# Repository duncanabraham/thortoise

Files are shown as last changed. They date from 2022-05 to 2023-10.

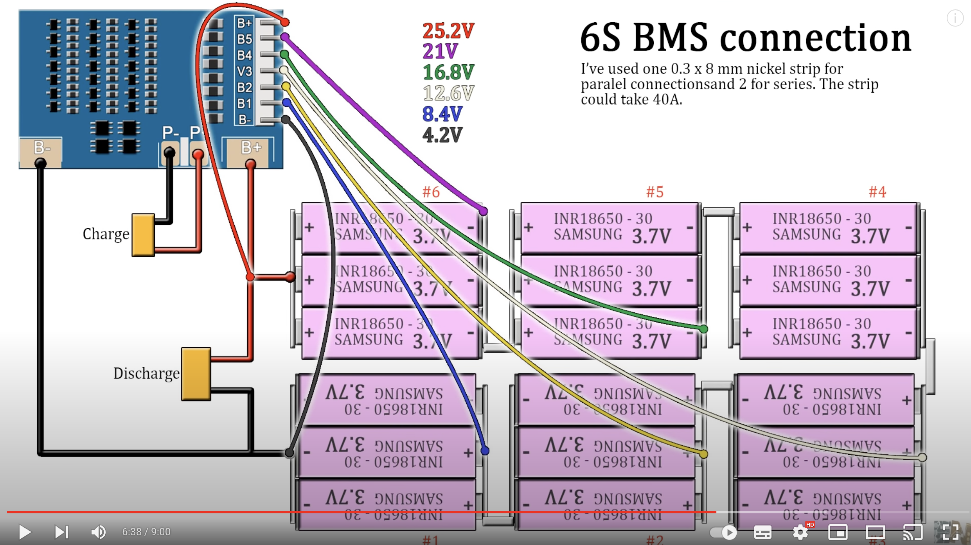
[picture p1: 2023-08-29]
docs/battery-bms.png

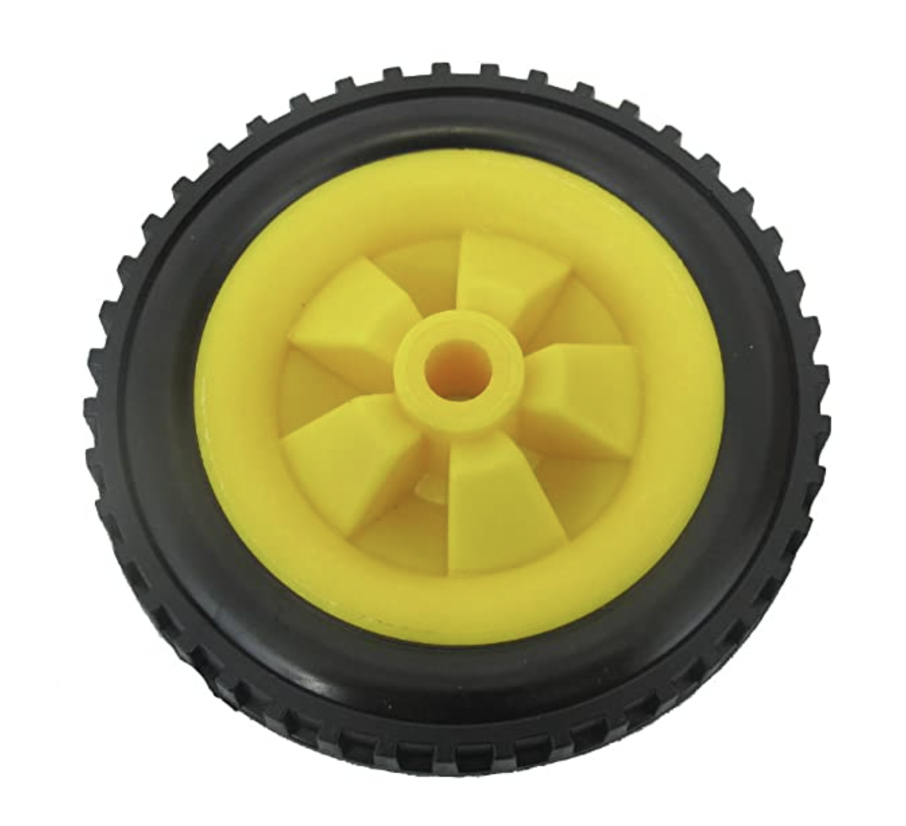
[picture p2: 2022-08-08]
docs/wheels/wheel.png

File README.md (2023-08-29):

# Thortoise
## the thinking tortoise

## What?
Simply put, this is a robotics project to animate a ~~4 legged~~ tracked garden crawler robot.  The goal
is to have a machine that can identify and remove weeds using some AI and also plant grass seed
in the bare patches using the mulched weeds as nutrients.

## Installation
Just clone the repo and npm install .. the usual stuff.

You may have some trouble installing this on a non-Raspberry Pi device, that's just because the raspi-io, i2c-bus and johnny-five libraries may not be supported.
Just remove them from the package.json file before running:

```
npm i
```

After this you need to create your .env file:

```
cp .env-default .env
```
By default the code will use the mock driver which can be used without the physical hardware being connected.

If you want to see lots of numbers relating to the servo angles you need to add this to your .env file:

```
VERBOSE=true
```

## Tests
Hard to believe, I know, but there are tests available here:

```
npm test
```

You'll need mocha and chai installed globally:

```
npm i -g mocha chai
```

## Hardware
Servo driven quadruped with solar charger.
  * Raspberry Pi Zero 2W with hats:
      - servo driver
      - GPS/GNSS
      - Sound
      - Canbus
      - Motor driver (not connected yet)

  * 3d printed limbs
  * Lead acid battery
  * Solar cells etc for changing

## Sensors
A number of sensors have been tested and drivers written to allow them to be added into the system, however not all will be used. Given
all the sensors are i2c based there's a common i2c base library which all the sensors extend.

To reuse the sensors outside of this project, you'll need to remove the inheritance from the Feature class:
```
class I2cBase extends Feature { <-- Remove "extends Feature"
  constructor (options = {}, additional = {}) {
    super({ ...featureOptions, ...options }) <-- Remove this line
    
```
A full list of sensors can be found in the readme file in the [lib/i2c folder](lib/i2c/README.md)

## Software
Lets buck the trend and not use ROS! How about some custom robot code with a redis channel
to allow communication between component parts which could be written in different languages
depending on the task at hand ... or maybe just write it all in good ol' JS!

## The basic components


## A still from a video of the leg moving in a circular gait:


A year later and the legs have gone.  Long story short, the servo's for a walking robot need to be heavy duty which come with a heavy duty price tag.  I decided to switch to a tracked design!

Having tracks means the machine can be heavier and bigger and work is ongoing to 3d print all the structural parts.

As soon as the mechanics of it are constructed I'll get some photos on here and start talking about expectations and features.  Also from an electronics perspective there are some design ideas that will impact the way the code operates.

Watch this space ....

Soooo here we go, I've 3d printed two 64:1 gearboxes using the design from this video: https://www.youtube.com/watch?v=G0DcM60lWSw&t=14s and modified the design to house my motors.  The motors are GARTT ML 5010 300KV with a rated power output of 800W.  The motors were taller than those in the video requiring the black shim you see in the following image, the mounting holes had different spacing and I needed a bigger hole for the cables I'd already soldered 3-way xt60 sockets on and I didn't want to take them off!!



The motors are to be connected to an ODrive motor controller which needs feedback from an encoder. After a couple of minutes with a vernier caliper and OPENScad I'd knocked up an encoder mount that would use the motor mount bolts to secure it in place.  I was happy with this approach and even happier when it was all installed and looking awesome.  The encoder is an AS5047P which has a rated CPR of 4096 but requires the Odrive to be configured as 4000. A magnet is glued to the back of the motor shaft. 4000 steps per turn is an accuracy of 0.09 degrees per step but with the added gearbox this is 0.001 degrees per step which is way more accurate than I need but made me wonder about making an EQ telescope mount .... one day ...





After completion of the main chassis it was time start working on the eletrics.  The motors are high power, as in >30A, so I need to be careful that any switching can handle that sort of current.  To this end I'd bought a 24v 200A relay for the last robot and again was able to reuse this. A low current switch is mounted in the "carry handle" and the wiring routed through the handle to the relay. At present it's a simple case of when the switch is on the Odrive is on but this may change later to allow the "brain" to turn the ODrive off when in power save mode.



It looks messy at the moment but there's a lot of baking soda to shake out of the frame when the gluing process has been completed.  The problem with baking soda is it falls through the cracks and I'm considering using hot glue to seal one side of the joints and baking soda and superglue the other.  I've also see a video showing graphite and superglue as an alternative and I may have a look into this to see if the results are better/stronger.

So with the power cables in place, and the ODrive connected to my PC for direct control, I was finally able to get both motors working at the same time.  Here's a still from the video:



There is a design flaw, which is not entirely of my making, but maybe I should have addressed it.  The gearbox housings are round and I'm going to apply torque to the end, what is going to happen to the gearbox!! My chassis design is a clamshell, so the upper section is a mirror of the lower section and when bolted in place, with some pads on the motors, I can apply a clamping force to the gearbox.  Only time will tell if this is going to be strong enough but in hindsight, when I was modifying the gearbox design I should have added lugs to allow it to be bolted in place ... I may still revisit this.

So here we are, chassis complete, main power control in place, the next step will be to add an enclosure to fit inside the chassis to hold the odrive, pi zero (radxa not raspberry) and power supply. This will provide another level of protection to the important parts should I have water (I have dogs, it could be yellow water) ingress.

I'm also going to reprint the drive cogs as I went with a hexagonal, work like a wrench, approach but again 20:20 hindsight shows that wheels should be round - who knew?

Not round vs Round:



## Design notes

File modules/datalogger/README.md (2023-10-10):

# Data Logger

this is currently running on dev3

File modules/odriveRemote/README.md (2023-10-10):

# Odrive Remote

This runs on the Radxa Zero and performs motor control through an API

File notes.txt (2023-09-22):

Given the robot is approx 500mm square perhaps the grid dimensions should match so each square in 
the grid represents one place where the robot can sit.

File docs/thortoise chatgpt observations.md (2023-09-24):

### 1. Object Recognition and Mapping:

- **Camera and Sensors**: A camera and additional sensors will be essential for object recognition.
- **AI Model**: Implement an AI model capable of identifying plants, watering cans, bare patches, etc., from the camera feed.
- **Object Logger**: Log the positions of recognized objects on the map along with additional metadata like timestamps.

### 2. Decision-Making:

- **Goal Prioritization**: The robot needs to prioritize between different tasks like trimming grass, seeding, researching, etc.
- **Event-Driven Architecture**: Create event triggers based on AI camera identification. For example, when a plant is identified, it triggers a 'SearchForSimilarPlants' event.

### 3. Action Execution:

- **Command Queue**: Extend your existing command queue to handle new types of actions like 'PlantSeeds', 'TrimGrass', etc.
- **Resource Management**: Ensure the robot is aware of its resource limitations (battery life, seed inventory, etc.)

### 4. Learning and Research:

- **Chat API**: Use a chat API to discover information about items found. The robot could query the API for details on how to care for a newly discovered plant species.
- **Learning Loop**: Implement a learning mechanism where the robot refines its decision-making or action execution based on the results of its research.

### 5. Lawn Maintenance:

- **Health Assessment**: Implement algorithms to assess the health of the lawn. This could be a combination of visual cues (brown patches) and sensor data (soil moisture).
- **Adaptive Scheduling**: The robot could adjust its schedule based on the health of the lawn, weather conditions, and other external factors.

### 6. User Interface:

- **Human Overrides**: Keep an option for manual overrides and emergency stops.
- **Monitoring Dashboard**: A dashboard where you can monitor all of the robot’s activities, statuses, and discovered objects.

The architecture you've chosen for the robot seems solid:

1. **ML5010 Drone motors with 64:1 gearboxes**: This provides both speed and torque, ideal for a robot that needs to move efficiently and perform tasks like planting or trimming grass.
2. **Odrive Motor Controller**: A good choice for precision control of your motors.
3. **Radxa Zero**: Responsible for motor control and status LEDs, a quad-core SBC that should manage these tasks quite well.
4. **Raspberry Pi 4**: The main computational unit, responsible for sensor data processing, decision-making, and also serving as a Wi-Fi hotspot for internal and external communication.
5. **Sensor Array**: A comprehensive list of sensors to help the robot navigate and understand its environment.
6. **Power Management**: Using solar panels and LIPO batteries, with channel monitoring to ensure the system remains powered or safely shuts down when needed.
7. **TPU for Machine Learning**: This is a great addition for offloading AI-related processing tasks, freeing up CPU cycles for other things.
8. **AI Camera**: This should be particularly useful for object recognition and distance estimation, important for tasks like identifying plants and obstacles.
9. **Pub/Sub architecture using Redis**: A scalable choice for message-passing within the robot and potentially to external systems.

The internal Wi-Fi network can be a robust solution for real-time control and data sharing between the various components. Using it for Pub/Sub via Redis should make the system very responsive. Plus, the ability to connect a tablet for remote control or logging data to an external database adds another layer of versatility.

### Heartbeat Signal for Radxa Zero

- **Timeout Mechanism**: If the Raspberry Pi 4 doesn't receive a heartbeat from the Radxa Zero within a certain timeframe, it should consider the Radxa to be offline.
- **Default Safe State**: The system could enter a default "safe" state where motors are disabled.
- **Alerts**: The system could also send out an alert (email, SMS, in-app notification, etc.) if the Radxa is not responding as expected.

### Detecting Dogs or Other Animals/Humans

- **AI-based Object Recognition**: Use your AI camera to identify living beings like humans or animals. The robot should stop all movement if such a detection is made.
- **Proximity Sensors**: In addition to visual identification, proximity or ultrasonic sensors can act as an extra layer of detection for nearby objects or beings.
- **Speed Limiting**: When the system detects a living being, it could reduce its speed to a minimum, so that even if there is contact, the impact is minimal.

### Emergency Stop Mechanism

- **Remote Control**: Always have a "kill switch" option available through the tablet or other remote control interfaces.
- **Local Button**: A physical button on the robot itself that can disable all systems immediately.

### Power Failures

- **Low Power Mode**: If the system detects low power levels, it could either safely return to a charging station if one exists or simply stop all operations until manually recovered.
- **Data Preservation**: Before shutting down due to low power, try to preserve essential data to make recovery smoother.

### Monitoring and Alerts

- **Regular System Checks**: Have the system constantly monitor its own health (battery, motor status, sensor status, etc.) and alert if something's not right.
- **External Monitoring**: If possible, set up an external system to monitor the robot's operational status.

By taking these precautions, you'll add an essential layer of safety to your robot, making it better equipped to operate autonomously in a dynamic environment.

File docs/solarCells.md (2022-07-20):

# How to get 17 cells around the inside of dome

external diameter: 400mm
internal diameter: 394mm

solar cell width: 55mm
solar cell height: 110mm

## Outer
* Each side has 17 facets so the angle at the centre is 21.18 degrees (21.18*17 = 360)

## Solving sides to imaginary centre as the sphere is incomplete!
* Solar cell + bracket = 120mm
* distance to solar cell = 200 - wall thickness - bracket thickness = 189

Side a = 120
Side b = 189
Side c = 189

Angle ∠A = 37.019° = 37°1'8" = 0.6461 rad
Angle ∠B = 71.491° = 71°29'26" = 1.24775 rad
Angle ∠C = 71.491° = 71°29'26" = 1.24775 rad

* therefore

## Solving e (distance from top edge to offset centre)
Side a = 160.83798
Side b = 40
Side c = 189

Angle ∠A = 40.763° = 40°45'47" = 0.71145 rad
Angle ∠B = 9.345° = 9°20'43" = 0.1631 rad
Angle ∠C = 129.892° = 129°53'30" = 2.26704 rad

therefore:
* distance to top edge = 160.838mm
* distance to bottom edge = 184.7mm  (sqrt(sqr(189) - sqr(40)))

## Solving the triangle from offset centre to cell base to cell top
Side a = 120
Side b = 160.838
Side c = 184.7

Angle ∠A = 39.896° = 39°53'44" = 0.69631 rad
Angle ∠B = 59.279° = 59°16'45" = 1.03462 rad
Angle ∠C = 80.825° = 80°49'31" = 1.41067 rad

* so the cell tilts inwards 59.2 degrees

## solving the radius to the top edge
Side a = 123.39651
Side b = 103.16086
Side c = 160.838

Angle ∠A = 50.104° = 50°6'14" = 0.87448 rad
Angle ∠B = 39.896° = 39°53'46" = 0.69632 rad
Angle ∠C = 90° = 1.5708 rad = π/2

* so the distance (radius) is 123.397mm

## facet size
* bottom edge = 71.88
* top edge = 55
* bottom offset = (bottomEdge - topEdge) / 2

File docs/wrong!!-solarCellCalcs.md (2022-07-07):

# solar cell calculations

## Outer
* Each side has 18 facets so the angle at the centre is 20 degrees (20*18 = 360)

Side a = 200
Side b = 200
Side c = 69.45927

Angle ∠A = 80° = 1.39626 rad = 4/9π
Angle ∠B = 80° = 1.39626 rad = 4/9π
Angle ∠C = 20° = 0.34907 rad = π/9

* the square across the circumference is 69.459mm

## inner
what size is the inner circle, given the panels are 55mm across

* Each side has 18 facets
* the square across has to be 55mm

Side a = 158.36619
Side b = 158.36619
Side c = 55

Angle ∠A = 80° = 1.39626 rad = 4/9π
Angle ∠B = 80° = 1.39626 rad = 4/9π
Angle ∠C = 20° = 0.34907 rad = π/9

* therefore the inner radius is 158.366

Side a = 158.366
Side b = 110
Side c = 200

Angle ∠A = 52.114° = 52°6'50" = 0.90956 rad
Angle ∠B = 33.243° = 33°14'36" = 0.5802 rad
Angle ∠C = 94.643° = 94°38'35" = 1.65183 rad

* so the bottom angle is 52.1 degrees and the top is 94.64 to the centre

* each large facet is 69.459 and the panel is 55 leaving 14.459 or 7.22 each side
* if the distance between the panels is 14.459mm then the 

Side a = 110
Side b = 110
Side c = 14.459

Angle ∠A = 86.232° = 86°13'54" = 1.50503 rad
Angle ∠B = 86.232° = 86°13'54" = 1.50503 rad
Angle ∠C = 7.537° = 7°32'12" = 0.13154 rad

* the angle between the panels is 7.53 degrees at the top

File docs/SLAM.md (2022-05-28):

# SLAM
## Simultaneous localisation and mapping

So how do we map the world around us into a 2d array that will allow us to:
* discover boundaries
* mark objects of interest
* navigate back to a known position

I think the discovery of boundaries will be a happy accident rather than an established goal.  Thortoise shouldn't set 
off to find the bounds it should just mark them when it finds them.

Our world will be 2d, however, we need to be aware of ground slope and level as this will play a part in navigation
as it will hinder movement in certain directions. Mapping altitude and slope will allow a contour map to be generated 
allowing easiest path planning to be perfomed.

Each element in the world array can contain an map element object.  This can store:
* Slope (from IMU)
* altitude (from GPS)
* actual coordinates (from GPS)
* distance to known features ?
* a photo of the ground at this point (a reference to a photo stored elsewhere)
* an AI analysis of the photo with object recognition
* a list of moveable objects seen at this location
* a list of fixed objects seen at this location

Eventually a complete map of the environment will be formed showing fixed objects, like walls, buildings, trees and 
moveable objects like garden furniture, dog toys and wildlife. The map will also contain a detailed view of the ground 
including plant life, lack of plant life and animal activity. The latter could include worm holes, ant colonies and the
dreaded dog poop.

## The primary objective(s)
1) To erradiate weeds from the lawn
2) To repair the lawn by planting seeds in barren patches
3) To use waste products to enrich the soil, including mulched weed and grass
4) To landscape by filling in divots and dents

## How will it work
We will have data from a number of sources which can all feed into an algorithm to give us an estimated position with 
a high degree of accuracy or reliability.

Sources:
* GPS
* IMU
* Camera(s)

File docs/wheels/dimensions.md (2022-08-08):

# Wheel dimensions

6" or 146mm Trolley wheel with 1/2" bore.

Image analysis:

Bore = 102 pixels
Width = 1108 pixels

Check image against dimensions:
146mm = 1108, therefore 1mm = 7.5 pixels
102 / 7.5 = 13.6mm

if 102 = 12.7mm therefore 1mm = 8 pixels per mm
1108 / 8 = 138.5mm

so it's somewhere between 7.5 and 8 pixels per mm, lets call it 7.75

* top triangle 147 pixels
* outer hub 200 pixels = 200/7.75 = 25.8, probably 1" or 25.4mm
* filled triangle base = 180 pixels = 23.2mm
* there are 5 spokes, the triangles appear to be pointy end in the centre
* Wheel hub = 750pixels = 750/7.75 = 96.77 which is probably 4" which is 101.6mm

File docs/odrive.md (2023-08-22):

In [153]: odrv0.clear_errors()

In [154]: odrv0.axis1.requested_state = AXIS_STATE_FULL_CALIBRATION_SEQUENCE

In [155]: odrv0.axis1.requested_state = AXIS_STATE_CLOSED_LOOP_CONTROL

In [156]: odrv0.axis1.controller.input_pos = 10

In [157]: odrv0.axis1.controller.input_pos = 2

In [158]: odrv0.axis1.controller.input_pos = 200

In [159]: odrv0.axis1.controller.input_pos = 180

In [160]: odrv0.axis1.controller.input_pos = 150

In [161]: odrv0.axis1.controller.input_pos = 130

In [162]: odrv0.axis1.controller.input_pos = 110

In [163]: odrv0.axis1.controller.input_pos = 0

Working after these below:

Connected to ODrive v3.6 207A39994D4D (firmware v0.5.6) as odrv0
In [1]: drv0.axis1.controller.config.control_mode
---------------------------------------------------------------------------
NameError                                 Traceback (most recent call last)
Cell In[1], line 1
----> 1 drv0.axis1.controller.config.control_mode

NameError: name 'drv0' is not defined

In [2]: odrv0.axis1.controller.config.control_mode
Out[2]: 3

In [3]: odrv0.axis1.controller.input_pos
Out[3]: 0.0

In [4]: odrv0.axis1.controller.config.control_mode
Out[4]: 3

In [5]: odrv0.axis1.controller.config.control_mode 2
  Cell In[5], line 1
    odrv0.axis1.controller.config.control_mode 2
                                               ^
SyntaxError: invalid syntax

In [6]: odrv0.axis1.controller.config.control_mode=2

In [7]: odrv0.axis1.requested_state = AXIS_STATE_FULL_CALIBRATION_SEQUENCE

In [8]: odrv0.axis1.requested_state = 8

In [9]: odrv0.axis1.controller.input_vel=32

In [10]: odrv0.axis1.controller.input_vel=0

In [11]: odrv0.axis1.controller.input_vel=8

In [12]: odrv0.axis1.controller.input_vel=16

In [13]: odrv0.axis1.controller.input_vel=0

In [14]:

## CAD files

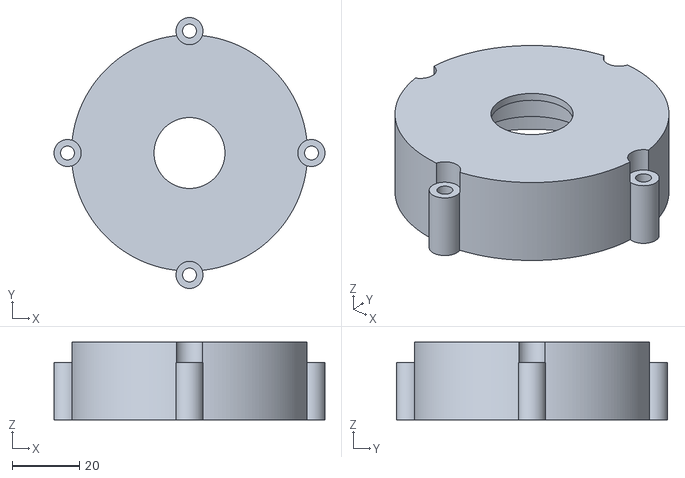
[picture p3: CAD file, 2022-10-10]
cad/gcode/gears-outputEnd.stl
80.3 x 80.3 x 23.0

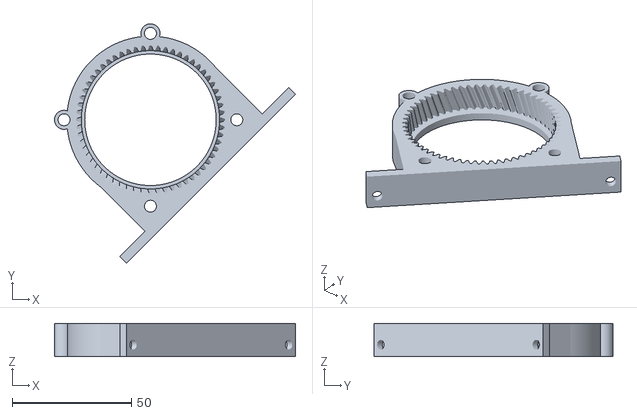
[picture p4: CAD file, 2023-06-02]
cad/gears-half-ring-b.stl
100.9 x 100.2 x 14.0

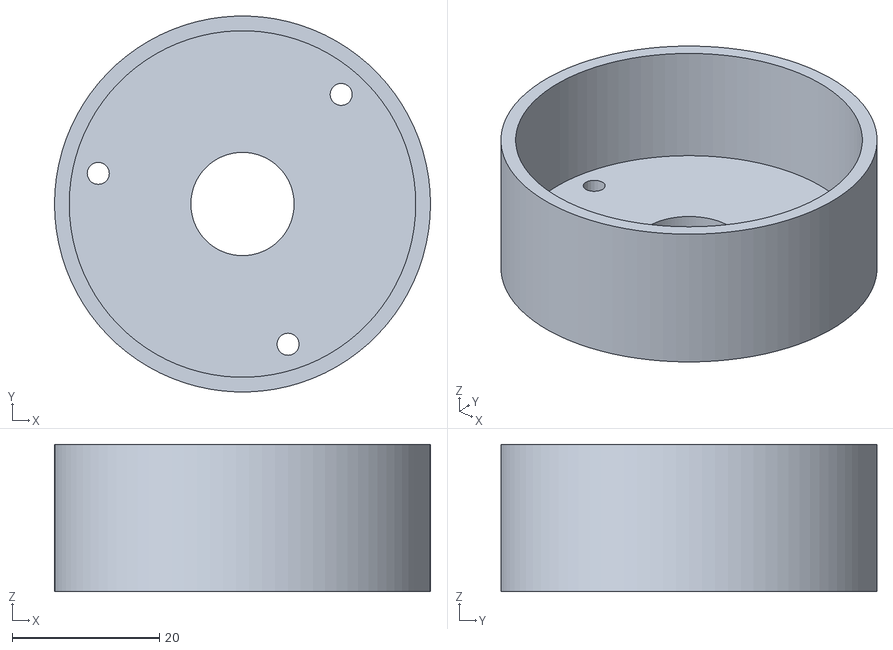
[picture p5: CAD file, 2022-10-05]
cad/gcode/gears-cap.stl
51.0 x 51.0 x 20.0

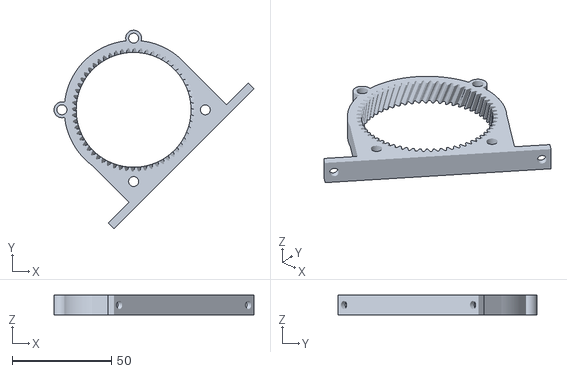
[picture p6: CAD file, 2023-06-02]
cad/gears-half-ring-a.stl
100.9 x 100.2 x 10.0

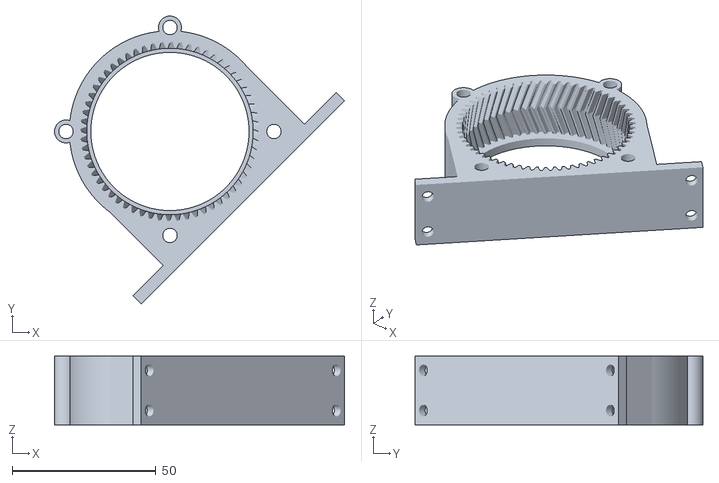
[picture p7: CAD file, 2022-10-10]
cad/gears-outer-ring.stl
100.9 x 100.2 x 24.0

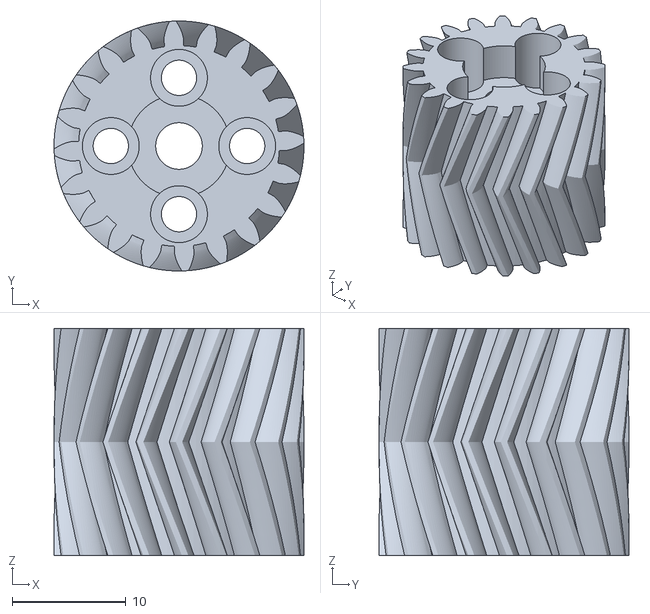
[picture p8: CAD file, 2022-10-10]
cad/gears-sungear.stl
22.0 x 22.0 x 20.0

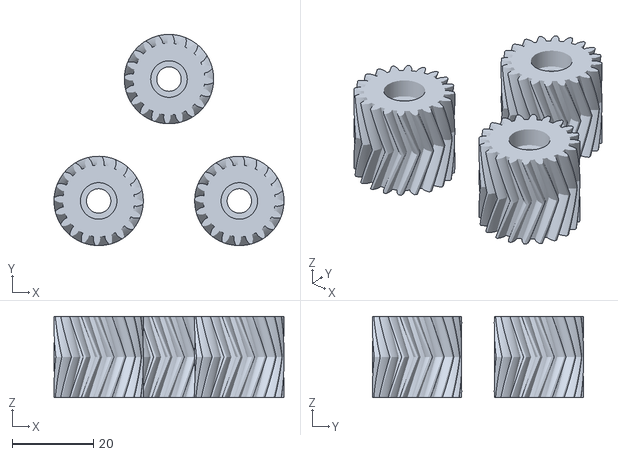
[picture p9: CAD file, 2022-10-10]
cad/gears-planets.stl
56.6 x 52.0 x 20.0

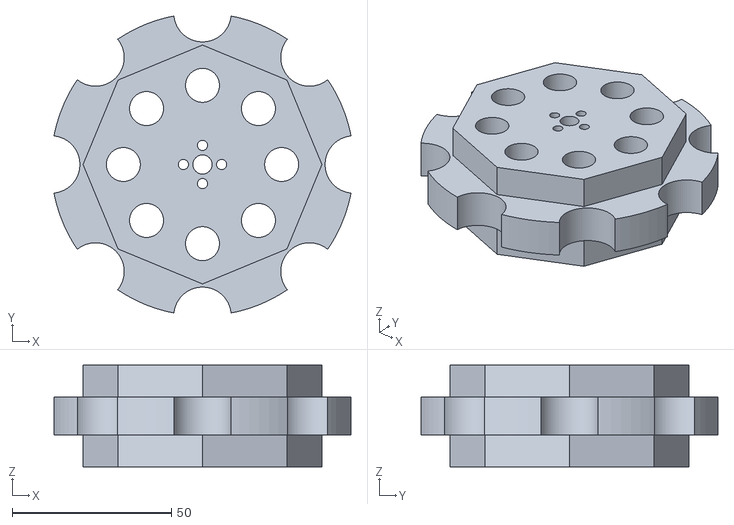
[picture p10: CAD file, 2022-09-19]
cad/spogget-drivecog.stl
93.2 x 93.3 x 32.0

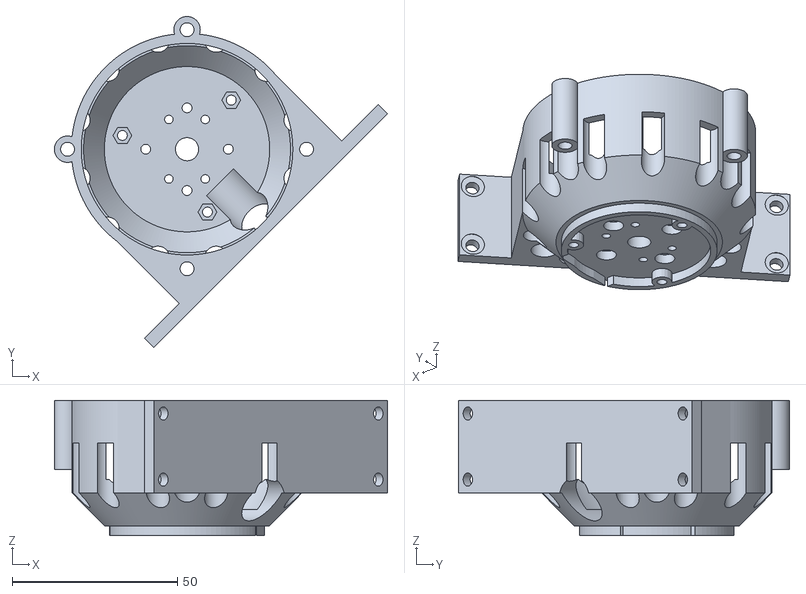
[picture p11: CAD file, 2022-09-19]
cad/gears-motorcell.stl
100.9 x 100.2 x 41.0

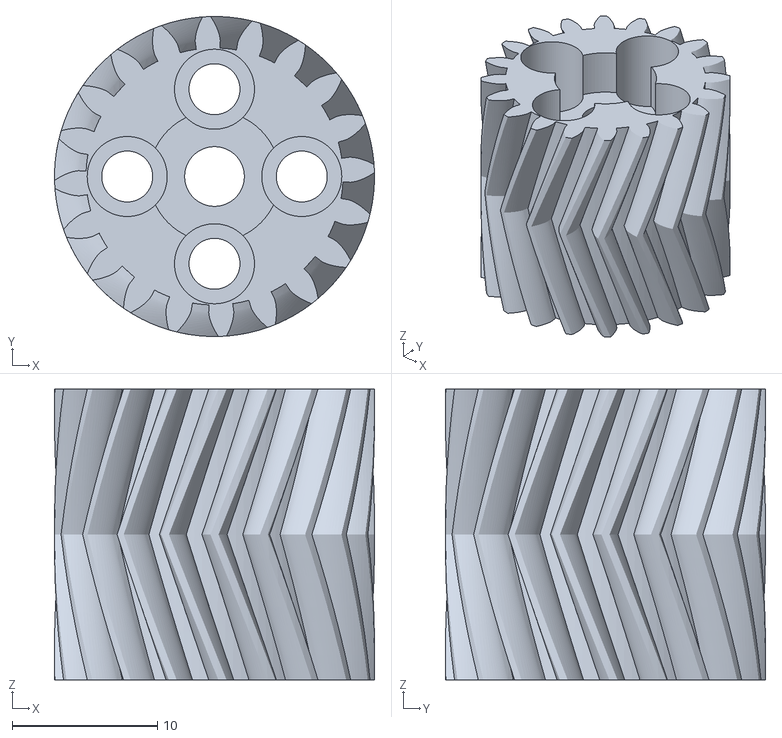
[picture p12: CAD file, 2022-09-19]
cad/gears-sun.stl
22.0 x 22.0 x 20.0

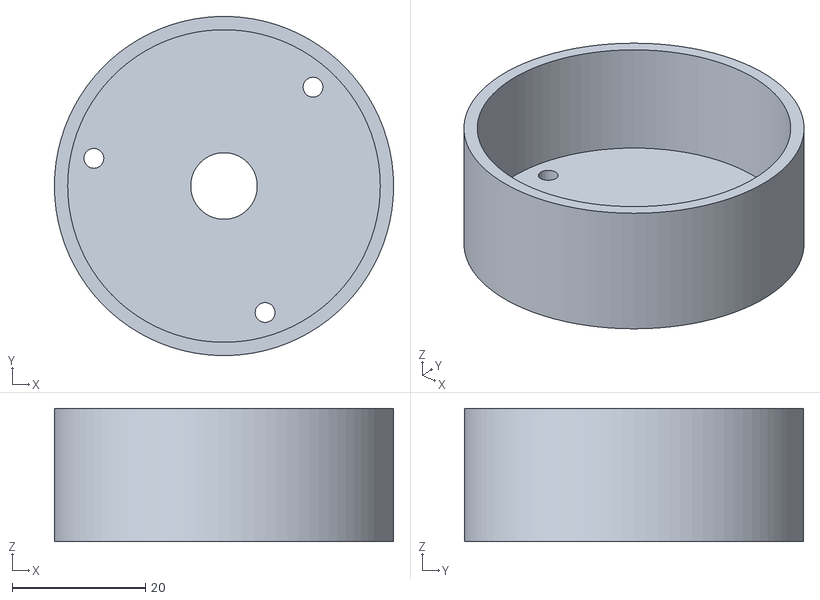
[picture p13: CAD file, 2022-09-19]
cad/gears-cap.stl
51.0 x 51.0 x 20.0

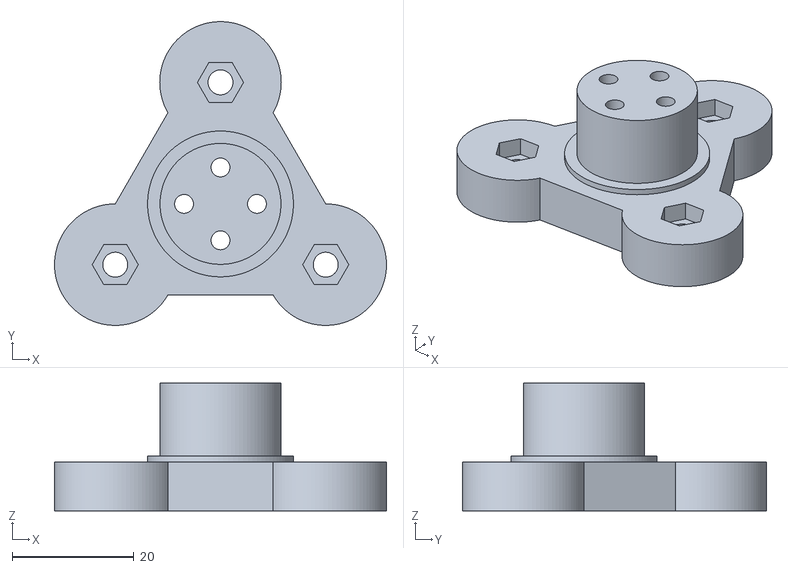
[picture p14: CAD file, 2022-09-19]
cad/gears-planetCarrier.stl
54.6 x 50.0 x 21.0

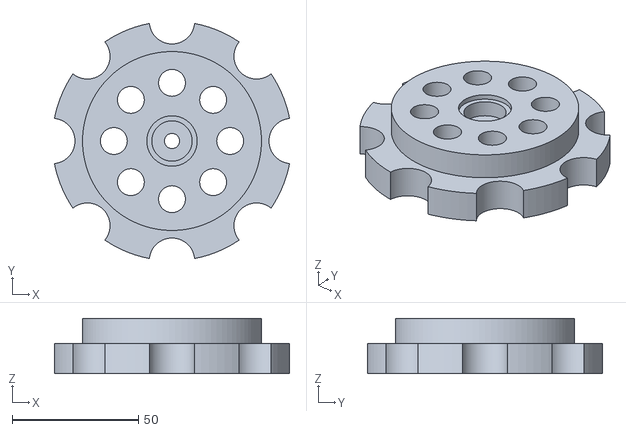
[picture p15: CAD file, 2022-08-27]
cad/spogget-cog-part1.stl
93.2 x 93.3 x 22.0

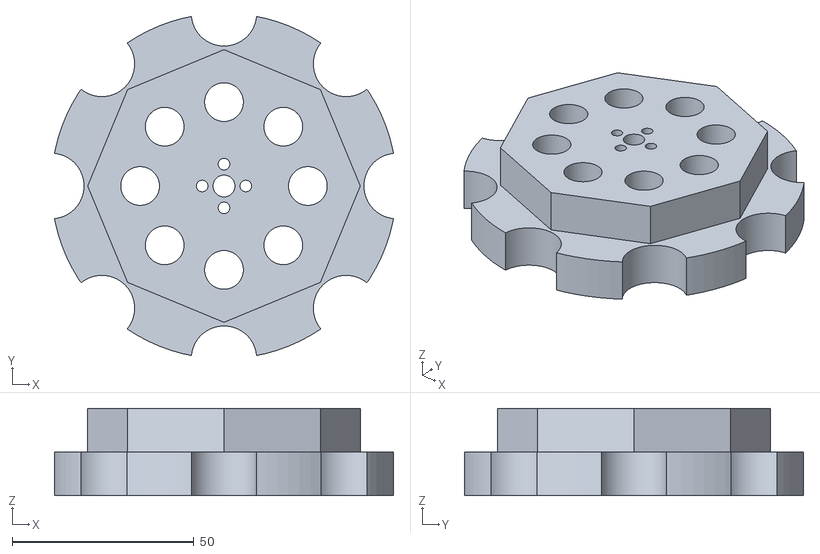
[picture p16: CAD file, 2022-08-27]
cad/spogget-driveCog-part1.stl
93.2 x 93.3 x 24.0

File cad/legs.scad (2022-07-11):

femur = 120;
knee = 120;
width = 20;
pitch = 100;

hwidth = width/2;
hpitch = pitch/2;


module topLimb(x,y,z,a) {
    difference() {
        union(){
            translate([x,y,z]) rotate([0,a,0]) cube([femur, width, width]);
            translate([x,y+hwidth,z]) rotate([0,a,0]) cylinder(d=width*1.5, h=10, $fn=36);
            
            translate([x+femur,y+hwidth,z+hwidth]) rotate([90,90,0]) cylinder(d=width*1.5, h=10, $fn=36);
        }
        union(){
//            translate([x+(femur/3)-1,y-1,z-(pitch/1.8)-1]) rotate([0,90,90]) cylinder(d=femur, h=width+2, $fn=360);
//            translate([x+(femur/3)-1,y-1,z+width+(pitch/1.8)-1]) rotate([0,90,90]) cylinder(d=femur, h=width+2, $fn=360);   
             translate([x+(femur/8)-1,y+width+1,z+width+(pitch/0.9)-1]) rotate([90,0,0]) cylinder(d=femur*2.01, h=width+2, $fn=360); 
        }
    }
}

module lowerLimb(x,y,z,a) {
}

module leftLeg() {
    topLimb(0,0,0,0);
}

module rightLeg() {
    topLimb(0,pitch,0,0);
}

leftLeg();
rightLeg();

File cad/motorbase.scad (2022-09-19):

length = 190;
width = 120;

level2Diameter = 210;

wallThickness = 5;
height = 22.5;
motorWidth = 15;
halfHeight = height /2;

axelBore = 10;
holeDistance = 20;
boreOffset = 12;
fixingOffset = 2.25;
fixingBore = 3;
fixingTop = height-fixingOffset;
reverseFixings = holeDistance + boreOffset;
wireHoleOffset = 40;
wireHoleBoreLength = 25;
wireHoleBoreHeight = 17;
wireHoleBoreHeightStart = (height - wireHoleBoreHeight) / 2;

batteryLength = 151;
batteryWidth = 51;
batteryHeight = 93;

boxHeight = wallThickness + (height * 2);

wheelDiameter = 70;
wheelWidth = 35;

midX=length / 2;
midY=width / 2;

startX = (length - batteryLength) / 2;
startY = (width - batteryWidth) / 2;


module level5() {
    layerHeight =18;
    offsetUp = 25+layerHeight+wallThickness;
    i2cMuxWidth=45;
    i2cMuxLength=81;
    
    lightSensorSpacing=8.5;
    
    powerMonitorWidth=18;
    powerMonitorLength=31.5;
    
    batteryChargerWidth=31.5;
    batteryChargerLength=61.3;
    
    
    difference(){
        union(){
            translate([0,0,boxHeight + wallThickness + offsetUp]) cube([length, width, wallThickness/2]);
            
            translate([(length/2)-80, 5, boxHeight + wallThickness + offsetUp-layerHeight]) 
                cylinder(d=10, h=layerHeight, $fn=90);
            translate([(length/2)-80, width-5, boxHeight + wallThickness + offsetUp-layerHeight]) 
                cylinder(d=10, h=layerHeight, $fn=90);
            translate([(length/2)+80, 5, boxHeight + wallThickness + offsetUp-layerHeight]) 
                cylinder(d=10, h=layerHeight, $fn=90);
            translate([(length/2)+80, width-5, boxHeight + wallThickness + offsetUp-layerHeight]) 
                cylinder(d=10, h=layerHeight, $fn=90);
            translate([(length/2)+30, width-5, boxHeight + wallThickness + offsetUp-layerHeight]) 
                cylinder(d=10, h=layerHeight, $fn=90);
            
            translate([length-80,width-wallThickness,boxHeight + wallThickness + offsetUp - layerHeight]) cube([80, wallThickness, layerHeight]);
            translate([length-wallThickness,width-wallThickness-20,boxHeight + wallThickness + offsetUp - layerHeight]) cube([wallThickness, 20, layerHeight]);
            translate([length-80,width-wallThickness-10,boxHeight + wallThickness + offsetUp - layerHeight]) cube([wallThickness, 10, layerHeight]);
            
        }
        union(){
            fixingHoles();
            
            // i2cMux Mounting
            translate([10, midY-(i2cMuxLength/2), boxHeight + wallThickness + offsetUp-layerHeight]) cylinder(d=2.5, h=50, $fn=90);
            translate([10, midY+(i2cMuxLength/2), boxHeight + wallThickness + offsetUp-layerHeight]) cylinder(d=2.5, h=50, $fn=90);
            translate([10+(i2cMuxWidth), midY-(i2cMuxLength/2), boxHeight + wallThickness + offsetUp-layerHeight]) cylinder(d=2.5, h=50, $fn=90);
            translate([10+(i2cMuxWidth), midY+(i2cMuxLength/2), boxHeight + wallThickness + offsetUp-layerHeight]) cylinder(d=2.5, h=50, $fn=90);
            
            // lightSensor S
            translate([5, midY-(lightSensorSpacing/2), boxHeight + wallThickness + offsetUp-layerHeight]) cylinder(d=5, h=50, $fn=90);
            translate([5, midY+(lightSensorSpacing/2), boxHeight + wallThickness + offsetUp-layerHeight]) cylinder(d=5, h=50, $fn=90);
            
            // lightSensor N
            translate([length-5, midY-(lightSensorSpacing/2), boxHeight + wallThickness + offsetUp-layerHeight]) 
                cylinder(d=5, h=50, $fn=90);
            translate([length-5, midY+(lightSensorSpacing/2), boxHeight + wallThickness + offsetUp-layerHeight])
                cylinder(d=5, h=50, $fn=90);
            
            // lightSensor E
            translate([midX-(lightSensorSpacing/2), 5, boxHeight + wallThickness + offsetUp-layerHeight]) 
                cylinder(d=5, h=50, $fn=90);
            translate([midX+(lightSensorSpacing/2), 5, boxHeight + wallThickness + offsetUp-layerHeight]) 
                cylinder(d=5, h=50, $fn=90);
            
            // lightSensor W
            translate([midX-(lightSensorSpacing/2), width-5, boxHeight + wallThickness + offsetUp-layerHeight]) cylinder(d=5, h=50, $fn=90);
            translate([midX+(lightSensorSpacing/2), width-5, boxHeight + wallThickness + offsetUp-layerHeight]) cylinder(d=5, h=50, $fn=90);
            
            // powerMonitor
            translate([length-20, midY-(powerMonitorLength/2), boxHeight + wallThickness + offsetUp-layerHeight]) cylinder(d=2.5, h=50, $fn=90);
            translate([length-20, midY+(powerMonitorLength/2), boxHeight + wallThickness + offsetUp-layerHeight]) cylinder(d=2.5, h=50, $fn=90);
            translate([length-20-(powerMonitorWidth), midY-(powerMonitorLength/2), boxHeight + wallThickness + offsetUp-layerHeight]) cylinder(d=2.5, h=50, $fn=90);
            translate([length-20-(powerMonitorWidth), midY+(powerMonitorLength/2), boxHeight + wallThickness + offsetUp-layerHeight]) cylinder(d=2.5, h=50, $fn=90);
            
            // batteryCharger
            translate([midX-(batteryChargerWidth/2), midY-(batteryChargerLength/2), boxHeight + wallThickness + offsetUp-layerHeight]) cylinder(d=2.5, h=50, $fn=90);
            translate([midX+(batteryChargerWidth/2), midY-(batteryChargerLength/2), boxHeight + wallThickness + offsetUp-layerHeight]) cylinder(d=2.5, h=50, $fn=90);
            
            translate([midX-(batteryChargerWidth/2), midY+(batteryChargerLength/2), boxHeight + wallThickness + offsetUp-layerHeight]) cube([batteryChargerWidth, 10, 50]);
            
            // Cable Slot 1
            slotWidth = batteryChargerWidth * 2.2;
            translate([59, midY-(slotWidth/2), boxHeight + wallThickness + offsetUp-layerHeight]) cube([12, slotWidth, 100]);
            
            // Cable Slot 2
            translate([length-60, midY-(batteryChargerWidth/2), boxHeight + wallThickness + offsetUp-layerHeight]) cube([10, batteryChargerWidth, 100]);
            
            // GPS Mount
            translate([length-10,20, boxHeight + wallThickness + offsetUp-layerHeight]) cylinder(d=6.4, h=25, $fn=90);
            
            // Switch 
            translate([length-40,width-wallThickness-1,boxHeight + wallThickness + offsetUp - layerHeight + 9]) rotate([0,90,90]) cylinder(d=12, h=10, $fn=90);
        }
    }
}

module level4() {   
    offsetUp = 25;
    difference(){
        union(){
            translate([0,0,boxHeight + wallThickness + offsetUp]) cube([length, width, wallThickness]);
            translate([midX,midY, boxHeight+wallThickness + offsetUp]) cylinder(d=level2Diameter*0.7, h=wallThickness, $fn=90);
            translate([startX - 5, startY - 5, boxHeight + wallThickness+wallThickness+wallThickness]) cube([batteryLength+10, batteryWidth+10, offsetUp-wallThickness]);
        }
        union(){
            translate([5, motorWidth + wallThickness, boxHeight-10+offsetUp]) cylinder(d=5, h=boxHeight, $fn=90);
            translate([5, width - (motorWidth + wallThickness), boxHeight-10+offsetUp]) cylinder(d=5, h=boxHeight, $fn=90);
            translate([length-5, motorWidth + wallThickness, boxHeight-10+offsetUp]) cylinder(d=5, h=boxHeight, $fn=90);
            translate([length-5, width - (motorWidth + wallThickness), boxHeight-10+offsetUp]) cylinder(d=5, h=boxHeight, $fn=90);
            battery();
            fixingHoles();
        }
    }
    cameraBracket();
}

module level3() {   
    offsetUp = 0;
    difference(){
        union(){
            translate([0,0,boxHeight + wallThickness + offsetUp]) cube([length, width, wallThickness]);
            translate([midX,midY, boxHeight+wallThickness + offsetUp]) cylinder(d=level2Diameter*0.9, h=wallThickness, $fn=90);
            translate([startX - 5, startY - 5, boxHeight + wallThickness + offsetUp]) cube([batteryLength+10, batteryWidth+10, 20]);
        }
        union(){
            translate([5, motorWidth + wallThickness, boxHeight-10+offsetUp]) cylinder(d=5, h=boxHeight, $fn=90);
            translate([5, width - (motorWidth + wallThickness), boxHeight-10+offsetUp]) cylinder(d=5, h=boxHeight, $fn=90);
            translate([length-5, motorWidth + wallThickness, boxHeight-10+offsetUp]) cylinder(d=5, h=boxHeight, $fn=90);
            translate([length-5, width - (motorWidth + wallThickness), boxHeight-10+offsetUp]) cylinder(d=5, h=boxHeight, $fn=90);
            battery();
            fixingHoles();
        }
    }
}

module battery() {
    translate([startX, startY, wallThickness]) color([0,0,0]) cube([batteryLength, batteryWidth, batteryHeight]);
}


module level2() {

    difference(){
        union(){
            translate([midX,midY, height+wallThickness]) cylinder(d=level2Diameter, h=wallThickness, $fn=90);
            translate([0,0,wallThickness+height]) cube([length, width, wallThickness]);
        }
        union(){
            fixingHoles();
            battery();
        }
    }
}
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

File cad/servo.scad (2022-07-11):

servoLength=42;
servoWidth=20;
servoHeight=36;
servoFlangeHeight=28;
fullLength=54;
flangeOffset = (fullLength - servoLength) / 2;
flangeMountHolesLength=50;
flangeHeight=2.5;
driveMountHeight=3;
driveMountWidth=10;

hipLength=60;
hipHeight=37;
hipWidth=60;


module servo(x,y,z) {
    difference(){
        union(){
            translate([x+flangeOffset,y,z]) cube([servoLength, servoWidth, servoHeight]);
            translate([x,y,z+servoFlangeHeight]) cube([fullLength, servoWidth, flangeHeight]);
            translate([x+fullLength-flangeOffset-16, y+10, z+servoHeight+3]) cylinder(d=5, h=7, $fn=36);
            translate([x+fullLength-flangeOffset-16, y+10, z+servoHeight]) cylinder(r=driveMountWidth, h=4, $fn=36);
            translate([x+fullLength-flangeOffset,y+4,z+4]) cube([flangeOffset, servoWidth-8, flangeHeight*2]);
        }
        union(){
            translate([x+2, y+5, z+servoFlangeHeight-1]) cylinder(d=4, h=4, $fn=36);
            translate([x+2, y+15, z+servoFlangeHeight-1]) cylinder(d=4, h=4, $fn=36);
            translate([x+fullLength-2, y+5, z+servoFlangeHeight-1]) cylinder(d=4, h=4, $fn=36);
            translate([x+fullLength-2, y+15, z+servoFlangeHeight-1]) cylinder(d=4, h=4, $fn=36);
        }
    }
}

module bracket(x,y,z) {
    difference(){
        union(){
            translate([x,y-3,z-1]) rotate([0,-90,-90]) color([0,1,0]) cube([hipHeight, fullLength+10, 2]);
            translate([x,y+servoWidth+1,z-1]) rotate([0,-90,-90]) color([0,1,0]) cube([hipHeight, fullLength+10, 2]);
            
            translate([x,y-3,z+servoFlangeHeight-6]) color([0,1,0]) cube([flangeOffset-1, servoWidth+4, 6]);
            translate([x,y-3,z+servoFlangeHeight-15]) color([0,1,0]) cube([flangeOffset-1, servoWidth+4, 4]);
            
            translate([x+fullLength,y-3,z+servoFlangeHeight-6]) color([0,1,0]) cube([flangeOffset-1+5, servoWidth+4, 8.5]);
            translate([x+fullLength-5,y-3,z+servoFlangeHeight-6]) color([0,1,0]) cube([flangeOffset-1+10, servoWidth+4, 6]);
            translate([x+fullLength-5,y-3,z+servoFlangeHeight-15]) color([0,1,0]) cube([flangeOffset-1+10, servoWidth+4, 4]);
            
            translate([x,y-3,z-3]) rotate([0,-90,-90]) color([0,1,0]) cube([2, fullLength+10, 26]);
            translate([x+fullLength-flangeOffset-16, y+10, z-8]) color([0,1,0]) cylinder(d=6, h=6, $fn=36);
        }
        union(){
            translate([x+2, y+5, z+servoFlangeHeight-20]) cylinder(d=4, h=24, $fn=36);
            translate([x+2, y+15, z+servoFlangeHeight-20]) cylinder(d=4, h=24, $fn=36);
            translate([x+fullLength-2, y+5, z+servoFlangeHeight-20]) cylinder(d=4, h=24, $fn=36);
            translate([x+fullLength-2, y+15, z+servoFlangeHeight-20]) cylinder(d=4, h=24, $fn=36);
        }
    }
}

module hip(x,y,z) {

}

module femur(x,y,z) {
    servo(x,y,z);
    bracket(x,y,z);
    
    rotate([0,0,225])
    difference(){
        x=x+0.5;
        y=y-20.5;
        union(){
            bracket(x,y,z);
            servo(x,y,z);
            rotate([0,0,66]) translate([x-22,y+10,z-3]) color([0,1,0]) cube([2,18.7,39]);
            rotate([0,-90,0]) translate([x-3.5,y-2,z-2]) color([0,1,0]) cube([2,25,18]);
        }
        union(){
            
            rotate([0,-90,0]) translate([x,y-25.8,z-2]) rotate([0,24,90]) color([0,1,0]) cube([20,10,30]);
            translate([x+fullLength+2,y-4,z+servoFlangeHeight-33]) cube([20,30,43]);
        }
    }
}

module knee(x,y,z) {
    difference(){
        rotate([0,0,0]) union(){
            translate([x,y-0.5,z-6]) color([0,0,1]) cube([90,30,hipHeight+17]);
            translate([x+fullLength-flangeOffset+42, y+14.5, z+servoHeight+7]) color([0,0,1]) cylinder(d=30, h=5, $fn=120);
            translate([x+fullLength-flangeOffset+42, y+14.5, z+servoHeight-42]) color([0,0,1]) cylinder(d=30, h=5, $fn=120);
        }
        union(){
            translate([x+55,y-1,z-1]) color([0,0,1]) cube([40,32,hipHeight+7]);
            translate([x+fullLength-flangeOffset+42, y+14.5, z+servoHeight+6]) color([0,0,1]) cylinder(d=5, h=10, $fn=120);
            translate([x+fullLength-flangeOffset+42, y+14.5, z+servoHeight-43]) color([0,0,1]) cylinder(d=16, h=7.5, $fn=120);
        }
    }
}


hip(0,0,0);
femur(0,0,0);
knee(-120,-30,-3);

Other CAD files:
cad/gears-output.stl
cad/spogget-driveCog-part2.stl
cad/spogget-cog-part2.stl
cad/spogget.stl
cad/wheel.scad
cad/F_shoulder.stl
cad/HexaLeg.3mf
cad/R_shoulder.stl
cad/Snow_Track1.STL
cad/baseplate.scad
cad/baseplate.stl
cad/basicBase.stl
cad/batterybox.scad
cad/bottomBracket.3mf
cad/bottomBracket.stl
cad/box-lid.stl
cad/box.scad
cad/box.stl
cad/box2.scad
cad/box2.stl
cad/box3.scad
cad/box3.stl
cad/box4.scad
cad/box4.stl
cad/brackets.scad
cad/cameraHolder.scad
cad/drive_spogget.stl
cad/femur.scad
cad/gears-outerRing.stl
cad/gears.scad
cad/gearsgen.scad
cad/lightHolder.scad
cad/lightHolder.stl
cad/motorbase.stl
cad/motorbaseCameraBracket.stl
cad/motorbaseLevel2.stl
cad/motorbaseLevel3.stl
cad/motorbaseLevel4.stl
cad/motorbaseLevel5.stl
cad/motorbaseLid.stl
cad/newBracket.scad
cad/solarcells-2.3mf
cad/solarcells-2.stl
cad/solarcells-new.stl
cad/solarcells.scad
cad/solarcells.stl
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

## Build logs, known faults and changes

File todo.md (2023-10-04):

# TODO

Still lots to do. How is this going to work?

* DONE - get bearing from IMU
* DONE - get location from GPS ??
* DONE - get direction from compass
* DONE - read light levels from sensors
* map location to internal map
* DONE - provide a way to save and load the map to disk
* DONE - provide a way to save and load the map from external server
* add commands to the api controller for:
  - Navigate to North, South, East, West
  - Walk: giving the current bearing and direction command, what coords should I move to
  - Goto: given destination coordinates, work out the next location to walk to. On the next turn, work it out again as the map could have been updated by then

* DONE - provide a list of commands, allow "goto" to enter a set of commands into the list
* let the system determine if a command is complete and we're ready to move on to the next command
* at each location take a picture of the ground (pi cam) and update the map
* Use the AI camera to provide object detection and use this to update the map
* Use the AI camera to determine distance to objects and use this to update the map
* Use a directive engine to determine what to do in the absense of API commands
* Use the sound card to announce what's going on
* Use the UART Hat GPIO to control the LEDs on the head
* DONE - Connect the solar cells to the charge controller
* DONE - needs work - Make a framework to support the solar cells
* DONE - needs more work around charging times - Use the charge monitor to determine charge, charging rate etc

** NOTE: I'm not sure this list is worth maintaining as it was written pre-legs!!

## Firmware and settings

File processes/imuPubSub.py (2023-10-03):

import time
import smbus
import math
import redis
import json

r = redis.Redis(host='localhost', port=6379, db=0)

Gyro  = [0,0,0]
Accel = [0,0,0]
Mag   = [0,0,0]
pitch = 0.0
roll  = 0.0
yaw   = 0.0
pu8data=[0,0,0,0,0,0,0,0]
U8tempX=[0,0,0,0,0,0,0,0,0]
U8tempY=[0,0,0,0,0,0,0,0,0]
U8tempZ=[0,0,0,0,0,0,0,0,0]
GyroOffset=[0,0,0]
Ki = 1.0
Kp = 4.50
q0 = 1.0
q1=q2=q3=0.0
angles=[0.0,0.0,0.0]
true                                 =0x01
false                                =0x00
# define ICM-20948 Device I2C address
I2C_ADD_ICM20948                     = 0x68
I2C_ADD_ICM20948_AK09916             = 0x0C
I2C_ADD_ICM20948_AK09916_READ        = 0x80
I2C_ADD_ICM20948_AK09916_WRITE       = 0x00
# define ICM-20948 Register
# user bank 0 register
REG_ADD_WIA                          = 0x00
REG_VAL_WIA                          = 0xEA
REG_ADD_USER_CTRL                    = 0x03
REG_VAL_BIT_DMP_EN                   = 0x80
REG_VAL_BIT_FIFO_EN                  = 0x40
REG_VAL_BIT_I2C_MST_EN               = 0x20
REG_VAL_BIT_I2C_IF_DIS               = 0x10
REG_VAL_BIT_DMP_RST                  = 0x08
REG_VAL_BIT_DIAMOND_DMP_RST          = 0x04
REG_ADD_PWR_MIGMT_1                  = 0x06
REG_VAL_ALL_RGE_RESET                = 0x80
REG_VAL_RUN_MODE                     = 0x01 # Non low-power mode
REG_ADD_LP_CONFIG                    = 0x05
REG_ADD_PWR_MGMT_1                   = 0x06
REG_ADD_PWR_MGMT_2                   = 0x07
REG_ADD_ACCEL_XOUT_H                 = 0x2D
REG_ADD_ACCEL_XOUT_L                 = 0x2E
REG_ADD_ACCEL_YOUT_H                 = 0x2F
REG_ADD_ACCEL_YOUT_L                 = 0x30
REG_ADD_ACCEL_ZOUT_H                 = 0x31
REG_ADD_ACCEL_ZOUT_L                 = 0x32
REG_ADD_GYRO_XOUT_H                  = 0x33
REG_ADD_GYRO_XOUT_L                  = 0x34
REG_ADD_GYRO_YOUT_H                  = 0x35
REG_ADD_GYRO_YOUT_L                  = 0x36
REG_ADD_GYRO_ZOUT_H                  = 0x37
REG_ADD_GYRO_ZOUT_L                  = 0x38
REG_ADD_EXT_SENS_DATA_00             = 0x3B
REG_ADD_REG_BANK_SEL                 = 0x7F
REG_VAL_REG_BANK_0                   = 0x00
REG_VAL_REG_BANK_1                   = 0x10
REG_VAL_REG_BANK_2                   = 0x20
REG_VAL_REG_BANK_3                   = 0x30

# user bank 1 register
# user bank 2 register
REG_ADD_GYRO_SMPLRT_DIV              = 0x00
REG_ADD_GYRO_CONFIG_1                = 0x01
REG_VAL_BIT_GYRO_DLPCFG_2            = 0x10  # bit[5:3]
REG_VAL_BIT_GYRO_DLPCFG_4            = 0x20  # bit[5:3]
REG_VAL_BIT_GYRO_DLPCFG_6            = 0x30  # bit[5:3]
REG_VAL_BIT_GYRO_FS_250DPS           = 0x00  # bit[2:1]
REG_VAL_BIT_GYRO_FS_500DPS           = 0x02  # bit[2:1]
REG_VAL_BIT_GYRO_FS_1000DPS          = 0x04  # bit[2:1]
REG_VAL_BIT_GYRO_FS_2000DPS          = 0x06  # bit[2:1]
REG_VAL_BIT_GYRO_DLPF                = 0x01  # bit[0]
REG_ADD_ACCEL_SMPLRT_DIV_2           = 0x11
REG_ADD_ACCEL_CONFIG                 = 0x14
REG_VAL_BIT_ACCEL_DLPCFG_2           = 0x10  # bit[5:3]
REG_VAL_BIT_ACCEL_DLPCFG_4           = 0x20  # bit[5:3]
REG_VAL_BIT_ACCEL_DLPCFG_6           = 0x30  # bit[5:3]
REG_VAL_BIT_ACCEL_FS_2g              = 0x00  # bit[2:1]
REG_VAL_BIT_ACCEL_FS_4g              = 0x02  # bit[2:1]
REG_VAL_BIT_ACCEL_FS_8g              = 0x04  # bit[2:1]
REG_VAL_BIT_ACCEL_FS_16g             = 0x06  # bit[2:1]
REG_VAL_BIT_ACCEL_DLPF               = 0x01  # bit[0]

# user bank 3 register
REG_ADD_I2C_SLV0_ADDR                = 0x03
REG_ADD_I2C_SLV0_REG                 = 0x04
REG_ADD_I2C_SLV0_CTRL                = 0x05
REG_VAL_BIT_SLV0_EN                  = 0x80
REG_VAL_BIT_MASK_LEN                 = 0x07
REG_ADD_I2C_SLV0_DO                  = 0x06
REG_ADD_I2C_SLV1_ADDR                = 0x07
REG_ADD_I2C_SLV1_REG                 = 0x08
REG_ADD_I2C_SLV1_CTRL                = 0x09
REG_ADD_I2C_SLV1_DO                  = 0x0A

# define ICM-20948 Register  end

# define ICM-20948 MAG Register
REG_ADD_MAG_WIA1                     = 0x00
REG_VAL_MAG_WIA1                     = 0x48
REG_ADD_MAG_WIA2                     = 0x01
REG_VAL_MAG_WIA2                     = 0x09
REG_ADD_MAG_ST2                      = 0x10
REG_ADD_MAG_DATA                     = 0x11
REG_ADD_MAG_CNTL2                    = 0x31
REG_VAL_MAG_MODE_PD                  = 0x00
REG_VAL_MAG_MODE_SM                  = 0x01
REG_VAL_MAG_MODE_10HZ                = 0x02
REG_VAL_MAG_MODE_20HZ                = 0x04
REG_VAL_MAG_MODE_50HZ                = 0x05
REG_VAL_MAG_MODE_100HZ               = 0x08
REG_VAL_MAG_MODE_ST                  = 0x10
# define ICM-20948 MAG Register  end

MAG_DATA_LEN                         =6

class ICM20948(object):
  def __init__(self,address=I2C_ADD_ICM20948):
    self._address = address
    self._bus = smbus.SMBus(1)
    bRet=self.icm20948Check()             #Initialization of the device multiple times after power on will result in a return error
    # while true != bRet:
    #   print("ICM-20948 Error\n" )
    #   time.sleep(0.5)
    # print("ICM-20948 OK\n" )
    time.sleep(0.5)                       #We can skip this detection by delaying it by 500 milliseconds
    # user bank 0 register 
    self._write_byte( REG_ADD_REG_BANK_SEL , REG_VAL_REG_BANK_0)
    self._write_byte( REG_ADD_PWR_MIGMT_1 , REG_VAL_ALL_RGE_RESET)
    time.sleep(0.1)
    self._write_byte( REG_ADD_PWR_MIGMT_1 , REG_VAL_RUN_MODE)  
    #user bank 2 register
    self._write_byte( REG_ADD_REG_BANK_SEL , REG_VAL_REG_BANK_2)
    self._write_byte( REG_ADD_GYRO_SMPLRT_DIV , 0x07)
    self._write_byte( REG_ADD_GYRO_CONFIG_1 , REG_VAL_BIT_GYRO_DLPCFG_6 | REG_VAL_BIT_GYRO_FS_1000DPS | REG_VAL_BIT_GYRO_DLPF)
    self._write_byte( REG_ADD_ACCEL_SMPLRT_DIV_2 ,  0x07)
    self._write_byte( REG_ADD_ACCEL_CONFIG , REG_VAL_BIT_ACCEL_DLPCFG_6 | REG_VAL_BIT_ACCEL_FS_2g | REG_VAL_BIT_ACCEL_DLPF)
    #user bank 0 register
    self._write_byte( REG_ADD_REG_BANK_SEL , REG_VAL_REG_BANK_0) 
    time.sleep(0.1)
    self.icm20948GyroOffset()
    self.icm20948MagCheck()
    self.icm20948WriteSecondary( I2C_ADD_ICM20948_AK09916|I2C_ADD_ICM20948_AK09916_WRITE,REG_ADD_MAG_CNTL2, REG_VAL_MAG_MODE_20HZ)
  def icm20948_Gyro_Accel_Read(self):
    self._write_byte( REG_ADD_REG_BANK_SEL , REG_VAL_REG_BANK_0)
    data =self._read_block(REG_ADD_ACCEL_XOUT_H, 12)
    self._write_byte( REG_ADD_REG_BANK_SEL , REG_VAL_REG_BANK_2)
    Accel[0] = (data[0]<<8)|data[1]
    Accel[1] = (data[2]<<8)|data[3]
    Accel[2] = (data[4]<<8)|data[5]
    Gyro[0]  = ((data[6]<<8)|data[7]) - GyroOffset[0]
    Gyro[1]  = ((data[8]<<8)|data[9]) - GyroOffset[1]
    Gyro[2]  = ((data[10]<<8)|data[11]) - GyroOffset[2]
    if Accel[0]>=32767:             #Solve the problem that Python shift will not overflow
      Accel[0]=Accel[0]-65535
    elif Accel[0]<=-32767:
      Accel[0]=Accel[0]+65535
    if Accel[1]>=32767:
      Accel[1]=Accel[1]-65535
    elif Accel[1]<=-32767:
      Accel[1]=Accel[1]+65535
    if Accel[2]>=32767:
      Accel[2]=Accel[2]-65535
    elif Accel[2]<=-32767:
      Accel[2]=Accel[2]+65535
    if Gyro[0]>=32767:
      Gyro[0]=Gyro[0]-65535
    elif Gyro[0]<=-32767:
      Gyro[0]=Gyro[0]+65535
    if Gyro[1]>=32767:
      Gyro[1]=Gyro[1]-65535
    elif Gyro[1]<=-32767:
      Gyro[1]=Gyro[1]+65535
    if Gyro[2]>=32767:
      Gyro[2]=Gyro[2]-65535
    elif Gyro[2]<=-32767:
      Gyro[2]=Gyro[2]+65535
  def icm20948MagRead(self):
    counter=20
    while(counter>0):
      time.sleep(0.01)
      self.icm20948ReadSecondary( I2C_ADD_ICM20948_AK09916|I2C_ADD_ICM20948_AK09916_READ , REG_ADD_MAG_ST2, 1)
      if ((pu8data[0] & 0x01)!= 0):
        break
      counter-=1
    if counter!=0:
      for i in range(0,8):
        self.icm20948ReadSecondary( I2C_ADD_ICM20948_AK09916|I2C_ADD_ICM20948_AK09916_READ , REG_ADD_MAG_DATA , MAG_DATA_LEN)
        U8tempX[i] = (pu8data[1]<<8)|pu8data[0]
        U8tempY[i] = (pu8data[3]<<8)|pu8data[2]
        U8tempZ[i] = (pu8data[5]<<8)|pu8data[4]
      Mag[0]=(U8tempX[0]+U8tempX[1]+U8tempX[2]+U8tempX[3]+U8tempX[4]+U8tempX[5]+U8tempX[6]+U8tempX[7])/8
      Mag[1]=-(U8tempY[0]+U8tempY[1]+U8tempY[2]+U8tempY[3]+U8tempY[4]+U8tempY[5]+U8tempY[6]+U8tempY[7])/8
      Mag[2]=-(U8tempZ[0]+U8tempZ[1]+U8tempZ[2]+U8tempZ[3]+U8tempZ[4]+U8tempZ[5]+U8tempZ[6]+U8tempZ[7])/8
    if Mag[0]>=32767:            #Solve the problem that Python shift will not overflow
      Mag[0]=Mag[0]-65535
    elif Mag[0]<=-32767:
      Mag[0]=Mag[0]+65535
    if Mag[1]>=32767:
      Mag[1]=Mag[1]-65535
    elif Mag[1]<=-32767:
      Mag[1]=Mag[1]+65535
    if Mag[2]>=32767:
      Mag[2]=Mag[2]-65535
    elif Mag[2]<=-32767:
      Mag[2]=Mag[2]+65535
  def icm20948ReadSecondary(self,u8I2CAddr,u8RegAddr,u8Len):
    u8Temp=0
    self._write_byte( REG_ADD_REG_BANK_SEL,  REG_VAL_REG_BANK_3) #swtich bank3
    self._write_byte( REG_ADD_I2C_SLV0_ADDR, u8I2CAddr)
    self._write_byte( REG_ADD_I2C_SLV0_REG,  u8RegAddr)
    self._write_byte( REG_ADD_I2C_SLV0_CTRL, REG_VAL_BIT_SLV0_EN|u8Len)

    self._write_byte( REG_ADD_REG_BANK_SEL, REG_VAL_REG_BANK_0) #swtich bank0
    
    u8Temp = self._read_byte(REG_ADD_USER_CTRL)
    u8Temp |= REG_VAL_BIT_I2C_MST_EN
    self._write_byte( REG_ADD_USER_CTRL, u8Temp)
    time.sleep(0.01)
    u8Temp &= ~REG_VAL_BIT_I2C_MST_EN
    self._write_byte( REG_ADD_USER_CTRL, u8Temp)
    
    for i in range(0,u8Len):
      pu8data[i]= self._read_byte( REG_ADD_EXT_SENS_DATA_00+i)

    self._write_byte( REG_ADD_REG_BANK_SEL, REG_VAL_REG_BANK_3) #swtich bank3
    
    u8Temp = self._read_byte(REG_ADD_I2C_SLV0_CTRL)
    u8Temp &= ~((REG_VAL_BIT_I2C_MST_EN)&(REG_VAL_BIT_MASK_LEN))
    self._write_byte( REG_ADD_I2C_SLV0_CTRL,  u8Temp)
    
    self._write_byte( REG_ADD_REG_BANK_SEL, REG_VAL_REG_BANK_0) #swtich bank0
  def icm20948WriteSecondary(self,u8I2CAddr,u8RegAddr,u8data):
    u8Temp=0
    self._write_byte( REG_ADD_REG_BANK_SEL,  REG_VAL_REG_BANK_3) #swtich bank3
    self._write_byte( REG_ADD_I2C_SLV1_ADDR, u8I2CAddr)
    self._write_byte( REG_ADD_I2C_SLV1_REG,  u8RegAddr)
    self._write_byte( REG_ADD_I2C_SLV1_DO,   u8data)
    self._write_byte( REG_ADD_I2C_SLV1_CTRL, REG_VAL_BIT_SLV0_EN|1)

    self._write_byte( REG_ADD_REG_BANK_SEL, REG_VAL_REG_BANK_0) #swtich bank0

    u8Temp = self._read_byte(REG_ADD_USER_CTRL)
    u8Temp |= REG_VAL_BIT_I2C_MST_EN
    self._write_byte( REG_ADD_USER_CTRL, u8Temp)
    time.sleep(0.01)
    u8Temp &= ~REG_VAL_BIT_I2C_MST_EN
    self._write_byte( REG_ADD_USER_CTRL, u8Temp)

    self._write_byte( REG_ADD_REG_BANK_SEL, REG_VAL_REG_BANK_3) #swtich bank3

    u8Temp = self._read_byte(REG_ADD_I2C_SLV0_CTRL)
    u8Temp &= ~((REG_VAL_BIT_I2C_MST_EN)&(REG_VAL_BIT_MASK_LEN))
    self._write_byte( REG_ADD_I2C_SLV0_CTRL,  u8Temp)

    self._write_byte( REG_ADD_REG_BANK_SEL, REG_VAL_REG_BANK_0) #swtich bank0
  def icm20948GyroOffset(self):
    s32TempGx = 0
    s32TempGy = 0
    s32TempGz = 0
    for i in range(0,32):
      self.icm20948_Gyro_Accel_Read()
      s32TempGx += Gyro[0]
      s32TempGy += Gyro[1]
      s32TempGz += Gyro[2]
      time.sleep(0.01)
    GyroOffset[0] = s32TempGx >> 5
    GyroOffset[1] = s32TempGy >> 5
    GyroOffset[2] = s32TempGz >> 5
  def _read_byte(self,cmd):
    return self._bus.read_byte_data(self._address,cmd)
  def _read_block(self, reg, length=1):
    return self._bus.read_i2c_block_data(self._address, reg, length)
  def _read_u16(self,cmd):
    LSB = self._bus.read_byte_data(self._address,cmd)
    MSB = self._bus.read_byte_data(self._address,cmd+1)
    return (MSB	<< 8) + LSB
  def _write_byte(self,cmd,val):
    self._bus.write_byte_data(self._address,cmd,val)
    time.sleep(0.0001)
  def imuAHRSupdate(self,gx, gy,gz,ax,ay,az,mx,my,mz):    
    norm=0.0
    hx = hy = hz = bx = bz = 0.0
    vx = vy = vz = wx = wy = wz = 0.0
    exInt = eyInt = ezInt = 0.0
    ex=ey=ez=0.0 
    halfT = 0.024
    global q0
    global q1
    global q2
    global q3
    q0q0 = q0 * q0
    q0q1 = q0 * q1
    q0q2 = q0 * q2
    q0q3 = q0 * q3
    q1q1 = q1 * q1
    q1q2 = q1 * q2
    q1q3 = q1 * q3
    q2q2 = q2 * q2   
    q2q3 = q2 * q3
    q3q3 = q3 * q3          

    norm = float(1/math.sqrt(ax * ax + ay * ay + az * az))     
    ax = ax * norm
    ay = ay * norm
    az = az * norm

    norm = float(1/math.sqrt(mx * mx + my * my + mz * mz))      
    mx = mx * norm
    my = my * norm
    mz = mz * norm

    # compute reference direction of flux
    hx = 2 * mx * (0.5 - q2q2 - q3q3) + 2 * my * (q1q2 - q0q3) + 2 * mz * (q1q3 + q0q2)
    hy = 2 * mx * (q1q2 + q0q3) + 2 * my * (0.5 - q1q1 - q3q3) + 2 * mz * (q2q3 - q0q1)
    hz = 2 * mx * (q1q3 - q0q2) + 2 * my * (q2q3 + q0q1) + 2 * mz * (0.5 - q1q1 - q2q2)         
    bx = math.sqrt((hx * hx) + (hy * hy))
    bz = hz     

    # estimated direction of gravity and flux (v and w)
    vx = 2 * (q1q3 - q0q2)
    vy = 2 * (q0q1 + q2q3)
    vz = q0q0 - q1q1 - q2q2 + q3q3
    wx = 2 * bx * (0.5 - q2q2 - q3q3) + 2 * bz * (q1q3 - q0q2)
    wy = 2 * bx * (q1q2 - q0q3) + 2 * bz * (q0q1 + q2q3)
    wz = 2 * bx * (q0q2 + q1q3) + 2 * bz * (0.5 - q1q1 - q2q2)  

    # error is sum of cross product between reference direction of fields and direction measured by sensors
    ex = (ay * vz - az * vy) + (my * wz - mz * wy)
    ey = (az * vx - ax * vz) + (mz * wx - mx * wz)
    ez = (ax * vy - ay * vx) + (mx * wy - my * wx)

    if (ex != 0.0 and ey != 0.0 and ez != 0.0):
      exInt = exInt + ex * Ki * halfT
      eyInt = eyInt + ey * Ki * halfT  
      ezInt = ezInt + ez * Ki * halfT

      gx = gx + Kp * ex + exInt
      gy = gy + Kp * ey + eyInt
      gz = gz + Kp * ez + ezInt

    q0 = q0 + (-q1 * gx - q2 * gy - q3 * gz) * halfT
    q1 = q1 + (q0 * gx + q2 * gz - q3 * gy) * halfT
    q2 = q2 + (q0 * gy - q1 * gz + q3 * gx) * halfT
    q3 = q3 + (q0 * gz + q1 * gy - q2 * gx) * halfT  

    norm = float(1/math.sqrt(q0 * q0 + q1 * q1 + q2 * q2 + q3 * q3))
    q0 = q0 * norm
    q1 = q1 * norm
    q2 = q2 * norm
    q3 = q3 * norm
  def icm20948Check(self):
    bRet=false
    if REG_VAL_WIA == self._read_byte(REG_ADD_WIA):
      bRet = true
    return bRet
  def icm20948MagCheck(self):
    self.icm20948ReadSecondary( I2C_ADD_ICM20948_AK09916|I2C_ADD_ICM20948_AK09916_READ,REG_ADD_MAG_WIA1, 2)
    if (pu8data[0] == REG_VAL_MAG_WIA1) and ( pu8data[1] == REG_VAL_MAG_WIA2) :
        bRet = true
        return bRet
  def icm20948CalAvgValue(self):
    MotionVal[0]=Gyro[0]/32.8
    MotionVal[1]=Gyro[1]/32.8
    MotionVal[2]=Gyro[2]/32.8
    MotionVal[3]=Accel[0]
    MotionVal[4]=Accel[1]
    MotionVal[5]=Accel[2]
    MotionVal[6]=Mag[0]
    MotionVal[7]=Mag[1]
    MotionVal[8]=Mag[2]
    
if __name__ == '__main__':
  import time
  print("\nIMU Data Logger ...\n")
  MotionVal=[0.0,0.0,0.0,0.0,0.0,0.0,0.0,0.0,0.0]
  icm20948=ICM20948()
  while True:
    icm20948.icm20948_Gyro_Accel_Read()
    icm20948.icm20948MagRead()
    # icm20948.icm20948CalAvgValue()
    # icm20948.imuAHRSupdate(MotionVal[0] * 0.0175, MotionVal[1] * 0.0175,MotionVal[2] * 0.0175, MotionVal[3],MotionVal[4],MotionVal[5], MotionVal[6], MotionVal[7], MotionVal[8])
    # pitch = math.asin(-2 * q1 * q3 + 2 * q0* q2)* 57.3
    # roll  = math.atan2(2 * q2 * q3 + 2 * q0 * q1, -2 * q1 * q1 - 2 * q2* q2 + 1)* 57.3
    # yaw   = math.atan2(-2 * q1 * q2 - 2 * q0 * q3, 2 * q2 * q2 + 2 * q3 * q3 - 1) * 57.3
    mag   = math.atan2(Mag[1], Mag[0]) * 180/math.pi
    # print("\r\n /-------------------------------------------------------------/ \r\n")
    # print('\r\n Roll = %.2f , Pitch = %.2f , Yaw = %.2f\r\n'%(roll,pitch,yaw))
    # print('\r\nAcceleration:  X = %d , Y = %d , Z = %d\r\n'%(Accel[0],Accel[1],Accel[2]))  
    # print('\r\nGyroscope:     X = %d , Y = %d , Z = %d\r\n'%(Gyro[0],Gyro[1],Gyro[2]))
    # print('\r\nMagnetic:      X = %d , Y = %d , Z = %d'%((Mag[0]),Mag[1],Mag[2]))
    # print('\r\nHeading:       %d'%(mag))    
    data = {
      "Accel0": Accel[0],
      "Accel1": Accel[1],
      "Accel2": Accel[2],
      "Gyro0": Gyro[0],
      "Gyro1": Gyro[1],
      "Gyro2": Gyro[2],
      "Mag0": Mag[0],
      "Mag1": Mag[1],
      "Mag2": Mag[2],
      "Heading": mag
    }
    data_json = json.dumps(data)
    r.publish('ICM20948_data', str(data_json))
    time.sleep(0.5)
    

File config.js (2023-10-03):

require('dotenv').config()
const { version } = require('./package.json')
const path = require('path')

// const legDefaults = {
//   femurLength: 115,
//   tibiaLength: 130,
//   hipServoSettings: this.hipServo,
//   femurServoSettings: this.femurServo,
//   kneeServoSettings: this.kneeServo,
//   direction: 'stopped'
// }

const env = {
  ...process.env
}

// https://components101.com/motors/mg996r-servo-motor-datasheet- max angle 180 degrees however I've measured it (roughly) at 200 degrees
// const servosFrontLeft = { // calibrated
//   hipServoSettings: { pin: 0, range: [10, 20], startAt: 10, sleepAt: 10, standAt: 10 }, // done
//   femurServoSettings: { pin: 1, range: [90, 200], startAt: 90, sleepAt: 90, standAt: 90 },
//   kneeServoSettings: { pin: 2, range: [30, 200], startAt: 120, sleepAt: 120, standAt: 120 }
// }

// const servosFrontRight = { // calibrated
//   hipServoSettings: { pin: 3, range: [170, 180], startAt: 180, sleepAt: 180, standAt: 180 },
//   femurServoSettings: { pin: 4, range: [10, 80], startAt: 80, sleepAt: 80, standAt: 80 },
//   kneeServoSettings: { pin: 5, range: [10, 80], startAt: 80, sleepAt: 80, standAt: 80 }
// }

// const servosBackLeft = {
//   hipServoSettings: { pin: 6, range: [0, 210], startAt: 200, sleepAt: 200, standAt: 200 },
//   femurServoSettings: { pin: 7, range: [0, 180], startAt: 150, sleepAt: 150, standAt: 150 },
//   kneeServoSettings: { pin: 8, range: [0, 180], startAt: 120, sleepAt: 120, standAt: 120 }
// }

// const servosBackRight = {
//   hipServoSettings: { pin: 9, range: [5, 15], startAt: 10, sleepAt: 10, standAt: 10 },
//   femurServoSettings: { pin: 10, range: [0, 220], startAt: 35, sleepAt: 35, standAt: 35 },
//   kneeServoSettings: { pin: 11, range: [0, 180], startAt: 100, sleepAt: 100, standAt: 100 }
// }

// const legSettings = [
//   { id: 0, name: 'front-left', startPos: 0, ...legDefaults, ...servosFrontLeft },
//   { id: 1, name: 'front-right', startPos: Math.PI / 2, ...legDefaults, ...servosFrontRight },
//   { id: 2, name: 'back-left', startPos: Math.PI, ...legDefaults, ...servosBackLeft },
//   { id: 3, name: 'back-right', startPos: Math.PI * 1.5, ...legDefaults, ...servosBackRight }
// ]

// fPin and bPin are pins not GPIO numbers
// const wheelSettings = {
//   frontLeft: { speedChannel: 0, fPin: 7, bPin: 11 }, // GPIOAO_3 & GPIOAO_2
//   frontRight: { speedChannel: 1, fPin: 13, bPin: 19 }, // GPIOX_11 &  GPIOH_4
//   backLeft: { speedChannel: 2, fPin: 21, bPin: 23 }, // GPIOH_5 & GPIOH_7
//   backRight: { speedChannel: 3, fPin: 35, bPin: 37 } // GPIOAO_8 & GPIOAO_9
// }

const odriveSettings = {
  BANDWIDTH: 100,
  ENCODER_CPR: 4000,
  CURRENT_LIMIT: 20,
  VEL_LIMIT: 200,
  VEL_GAIN: 0.05,
  POS_GAIN: 0.5,
  INTEGRATOR: 0.007
}

const trackApiSettings = {
  address: '127.0.0.1',
  port: 3010
}

const i2cSettings = {
  i2cBus: 0x01
}

const options = {
  name: 'Thortoise',
  version,
  trackApiSettings,
  verbose: env.VERBOSE === 'true',
  env: env.ENVIRONMENT,
  dimensions: { // measure these, the navigation module will need to work out if it fits through/between/under a gap or obstacle
    width: 500,
    height: 400,
    length: 500
  }
}

const api = {
  port: 3000
}

const navigationSettings = { // each square on the grid represents a 500x500mm square in the real world
  gridWidth: 500,
  gridLength: 500,
  length: 9,
  width: 9,
  startX: 5,
  startY: 5
}

const cameraSettings = {
  mode: 'photo',
  output: path.join(__dirname, 'image.jpg'),
  width: 640,
  height: 480,
  nopreview: true
}

const ATCOMMANDS = {
  status: 'AT\r'
}

const keyManagerSettings = {
  keyServerUrl: 'http://datalog:3050'
}

module.exports = {
  env,
  options,
  api,
  navigationSettings,
  cameraSettings,
  i2cSettings,
  odriveSettings,
  ATCOMMANDS,
  keyManagerSettings
}

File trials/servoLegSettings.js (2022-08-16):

require('./common')
const Controller = require('../lib/ServoController')
const servoController = new Controller()
const delay = require('../lib/utils').delay

const { options: { legSettings } } = require('../config')

const servoNames = ['hipServoSettings', 'femurServoSettings', 'kneeServoSettings']

const testLeg = 0
const testServo = 0

console.log('legSettings', legSettings[testLeg])
const servo = servoController.addServo(legSettings[testLeg][servoNames[testServo]])
console.log('servo: ', servo)

// Sweep the servo from 10 to maxRange and back to 10
const run = async () => {
  servo.home()
  await delay(1000)
}

run()

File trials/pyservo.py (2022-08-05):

# Servo demo
import smbus
import time
import math

BOARD_I2C_ADDR = 0x40
CHANNEL_0_START = 0x06
CHANNEL_0_END = 0x08
CHANNEL_1_START = 0x0A
CHANNEL_1_END = 0x0C
CHANNEL_2_START = 0x0E
CHANNEL_2_END = 0x10
MODE1_REG_ADDR = 0
PRE_SCALE_REG_ADDR = 0xFE

bus = smbus.SMBus(3)

# Enable prescaler change
bus.write_byte_data(BOARD_I2C_ADDR, MODE1_REG_ADDR, 0x10)

# Set prescaler to 50Hz from datasheet calculation
bus.write_byte_data(BOARD_I2C_ADDR, PRE_SCALE_REG_ADDR, 0x80)
time.sleep(.25)

# Enable word writes
bus.write_byte_data(BOARD_I2C_ADDR, MODE1_REG_ADDR, 0x20)

angle=80
testServo=5


SERVO_CONSTANT = 2.295
pos = math.floor((angle * SERVO_CONSTANT) + 71)

def sleep():
  # Front Left
  bus.write_word_data(BOARD_I2C_ADDR, CHANNEL_0_START+(4 * 0), 0)
  bus.write_word_data(BOARD_I2C_ADDR, CHANNEL_0_END+(4 * 0), math.floor((20 * SERVO_CONSTANT) + 71))

  bus.write_word_data(BOARD_I2C_ADDR, CHANNEL_0_START+(4 * 1), 0)
  bus.write_word_data(BOARD_I2C_ADDR, CHANNEL_0_END+(4 * 1), math.floor((110 * SERVO_CONSTANT) + 71))

  bus.write_word_data(BOARD_I2C_ADDR, CHANNEL_0_START+(4 * 2), 0)
  bus.write_word_data(BOARD_I2C_ADDR, CHANNEL_0_END+(4 * 2), math.floor((120 * SERVO_CONSTANT) + 71))



  # Front Right
  bus.write_word_data(BOARD_I2C_ADDR, CHANNEL_0_START+(4 * 3), 0)
  bus.write_word_data(BOARD_I2C_ADDR, CHANNEL_0_END+(4 * 3), math.floor((180 * SERVO_CONSTANT) + 71))

  bus.write_word_data(BOARD_I2C_ADDR, CHANNEL_0_START+(4 * 4), 0)
  bus.write_word_data(BOARD_I2C_ADDR, CHANNEL_0_END+(4 * 4), math.floor((80 * SERVO_CONSTANT) + 71))

  bus.write_word_data(BOARD_I2C_ADDR, CHANNEL_0_START+(4 * 5), 0)
  bus.write_word_data(BOARD_I2C_ADDR, CHANNEL_0_END+(4 * 5), math.floor((110 * SERVO_CONSTANT) + 71))



def stand():
  # Front Left
  bus.write_word_data(BOARD_I2C_ADDR, CHANNEL_0_START+(4 * 0), 0)
  bus.write_word_data(BOARD_I2C_ADDR, CHANNEL_0_END+(4 * 0), math.floor((10 * SERVO_CONSTANT) + 71))

  bus.write_word_data(BOARD_I2C_ADDR, CHANNEL_0_START+(4 * 1), 0)
  bus.write_word_data(BOARD_I2C_ADDR, CHANNEL_0_END+(4 * 1), math.floor((170 * SERVO_CONSTANT) + 71))

  bus.write_word_data(BOARD_I2C_ADDR, CHANNEL_0_START+(4 * 2), 0)
  bus.write_word_data(BOARD_I2C_ADDR, CHANNEL_0_END+(4 * 2), math.floor((170 * SERVO_CONSTANT) + 71))



  # Front Right
  bus.write_word_data(BOARD_I2C_ADDR, CHANNEL_0_START+(4 * 3), 0)
  bus.write_word_data(BOARD_I2C_ADDR, CHANNEL_0_END+(4 * 3), math.floor((190 * SERVO_CONSTANT) + 71))

  bus.write_word_data(BOARD_I2C_ADDR, CHANNEL_0_START+(4 * 4), 0)
  bus.write_word_data(BOARD_I2C_ADDR, CHANNEL_0_END+(4 * 4), math.floor((30 * SERVO_CONSTANT) + 71))

  bus.write_word_data(BOARD_I2C_ADDR, CHANNEL_0_START+(4 * 5), 0)
  bus.write_word_data(BOARD_I2C_ADDR, CHANNEL_0_END+(4 * 5), math.floor((30 * SERVO_CONSTANT) + 71))


stand()

time.sleep(3)

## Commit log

2022-05-15 added easing for motor curve control
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2022-05-15 just one leg and 20 times per second
2022-05-17 servo agnostic, added run loop
2022-05-18 add min and max positions to servos
2022-05-18 fixed servoDriver
2022-05-18 fixed invalid i2c channel
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2022-05-20 updated test to run 3 servos
2022-05-21 added kinematic models and tests
2022-05-21 fixed some issues with the inverse kinematics and added test
2022-05-23 fixed servo addressing issue
2022-05-23 reworked the kinematics
2022-05-24 kinematics test with leg control
2022-05-24 oops, was set to mock driver
2022-05-25 changed all the maths and broke something
    [kinematicstest.js]
2022-05-25 minor updates to kinematics test
2022-05-26 updated kinematics test ready for testing
2022-05-26 need to fix NaN in kinematics:move
    [kinematicstest.js]
2022-05-26 4 legs moving at the same time
2022-05-26 exported kinematics for plotting and added plot
2022-05-27 trying a new reverse option
    [config.js]
2022-05-27 fixed legs not moving
2022-05-27 fixed out of bounds on leg movements
    [config.js]
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2022-05-27 each leg keeps track of its own step
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2022-05-27 added a spreadsheet
    [leg-positions.ods]
2022-05-27 fixed broken test
    [leg-positions.ods]
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2022-06-12 added cad drawings
    [batterybox.scad, topLid.stl]
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2022-06-13 added temp and pressure to brain
2022-06-13 changed the way the sensors are read
2022-06-14 added IMU support
    [basicBase.stl, batterybox.scad]
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2022-06-14 imu debugged and working
2022-06-14 added new devices to brain
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2022-06-14 Trying to sort out the PWM controller code
2022-06-16 commented out the detached devices
2022-06-16 added cad for baseplate
    [baseplate.scad, baseplate.stl]
2022-06-16 removed GPIO module as this is now separate and updated config for different servo settings for Front and Back
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2022-06-17 new servo start positions
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2022-06-17 all 4 legs, no sleep
2022-06-17 back to 2 legs
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2022-06-21 leg inits stand position
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2022-06-21 home legs on init
2022-06-22 updated ICM20948 driver and test script
2022-06-22 added board id check
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2022-06-22 Added a compass driver
2022-06-23 temperature correction
2022-06-24 added light sensor array
2022-06-24 light sensors test routine
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2022-06-27 bearing to 2 decimals
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2022-06-28 set single sensor for testing
2022-06-28 round sensor value to 3 decimal places
2022-06-28 updated the compass bearings to use coords
2022-06-28 checking the light sensor commands
2022-06-28 use coords for bearing calculation
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2022-06-28 and show the temperature
2022-06-29 calibration values for x,y,z
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2022-06-29 calibrated bearings using min and max sensor values
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2022-06-29 work out the calibration values as we go
2022-06-29 calculations for bearing from Bob project
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2022-06-29 added method from arduino
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2022-06-30 switch east and west
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2022-06-30 speed up leg movements
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2022-06-30 minor changes to leg loops
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2022-07-07 added cad and angle calcs for solar cell holders
    [solarcells.scad, solarcells.stl]
2022-07-08 updated cad
    [solarcells.scad, solarcells.stl]
2022-07-11 changed solar cell angles
    [solarcells.scad, solarcells.stl]
2022-07-12 modded cell holder
    [solarcells-2.stl, solarcells.scad, solarcells2.scad]
2022-07-13 some cad updates
    [solarcells2.scad, solarclips.scad]
2022-07-13 more cad
    [solarcells2.scad]
2022-07-14 new cad
    [solarcells-2.3mf, solarcells-new.stl]
2022-07-14 new stuff
    [brackets.scad, topWasher.scad, topWasher.stl]
2022-07-20 mostly cad
    [HexaLeg.3mf, bottomBracket.3mf, bottomBracket.stl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]
2022-07-22 added voltage monitor to light sensors array
2022-07-23 renamed lightSensors to reflect general purpose sensor array
2022-07-24 cad etc
    [baseplate.scad, batterybox.scad, box-lid.stl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]
2022-07-25 new lightsensor code
    [F_shoulder.stl, R_shoulder.stl, box.scad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]
2022-07-26 switch to one shot reading
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2022-07-29 hide imu until fitted
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2022-07-30 new qmc5883l driver and integration
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2022-08-02 mount plate
    [box4.scad]
2022-08-03 modified servo test script
2022-08-03 basic init on the pca driver
2022-08-03 servo reset
2022-08-04 added servo constant to driver
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2022-08-04 modified the servo config file
2022-08-04 updated servo config with default pins
2022-08-04 python script updated to allow individual servo testing
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2022-08-04 oops next servo please
2022-08-08 light sensors new address
2022-08-08 new light sensor address
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2022-08-12 basic 4 wheel drive base
    [motorbase.scad, motorbase.stl, motorbaseLid.stl]
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2022-08-23 cad - adjustable Track fixings
    [spogget-nase.stl, spogget-nose.stl, spogget.scad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]
2022-10-05 some cad
    [gears-outer-ring.stl, gears-planets.stl, gears-sungear.stl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]
2023-08-19 added micropython scripts to interface with the odrive
    [gears.scad]
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2023-08-22 we don't need an interface to the pico because we're driving the odrive directly from the radxa zero
2023-08-22 removing track code and embedding odrive
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2023-09-17 modified: index.js modified: lib/i2c/i2cBase.js renamed: trials/odriveRemote/lib/log.js -> lib/log.js modified: lib/odrive.js modified: lib/runCommand.js modified: lib/serial.js modified: trials/dump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
2023-09-19 added a script to see if the sensor is responding
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2023-09-21 updated imuPubSub.py to not output data as this is now running in the background
2023-09-21 changed the pub channel to match the device name
2023-09-21 changed the way external devices are linked in and how the subscribe to data
2023-09-21 turned off sensor mux as it's not connected
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2023-09-26 adding i2c check to see if device exists
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2023-10-02 update the correct data log!
    [config.js]
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2023-10-03 added threshhold to pitch as well as roll
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2023-10-04 moved odriveRemote to the modules folder and updated references
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2023-10-04 prevent anything else from interfering with the LEDs
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2023-10-04 only set LED states if they're passed in
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2023-10-11 added a WOMP on the power management check
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
